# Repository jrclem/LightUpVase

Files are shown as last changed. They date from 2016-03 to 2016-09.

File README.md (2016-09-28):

# LightUpVase
This is an Arduino based project to control light colors and animationd in a 3D printed vase and rose. I originally made it for my girlfriend as an anniversary gift, but I thought people might like to make their own.

The project uses the [Adafruit NeoPixel library](https://github.com/adafruit/Adafruit_NeoPixel) and it has been tested in an Arduino Uno board with an ATmega328P processor. It is compatible with the [Adafruit ProTrinket 5v](https://www.adafruit.com/products/2000).

The STL files for the [vase](../master/rose-vase_FINAL.stl) and [flower](../master/rose-petals_FINAL.stl) models are based on models from www.thingiverse.com. The vase is a remix of ["Wave Vase" by didierkl](http://www.thingiverse.com/thing:983438), and the flower is a remix of ["Make a rose for your girl" by hansliu](http://www.thingiverse.com/thing:663065). For more details about the 3D printing specifications visit my [thingiverse account](http://www.thingiverse.com/jrclem/designs). They will be available in the next few days.

A youtube playlist detailing the development process will be available [here](http://bit.ly/2cJCIvM).

###Operation:

1. Connect the power supply to the vase. (In this case using 5V, 2A)
2. Flip the slide switch to the "on" position. This will power the board and the NeoPixel Ring.
3. Click the pushbutton for less than 0.5s to flip through the vase's light animations.
4. Click the pushbutton for  more than 0.5s to flip through the flower's light animations.

*Note:*
Do not leave lights turned off while the slide switch in the "on" position for an extended period of time. The board will still be powered during this time.

###Supplies

1. 1x [Arduino ProTrinket 5v](https://www.adafruit.com/products/2000)
2. 1x [Arduino RGB Neopixel Ring 16x](https://www.adafruit.com/products/1463)
3. 1x [Arduino RGB Neopixel](https://www.adafruit.com/products/1260)
4. 1x 5.5mmx2.1mm female barrel jack power adapter
5. 1x slide switch
6. 1x 6mmx6mm push button
7. 1x 1000&mu;F capacitor
8. 2x 510&ohm; resistor
9. 3x battery contact plates (or a similar thin conductive metal)
10. 1x 5v, 2A power supply with 5.5mmx2.1mm plug
11. \~250g translucent PLA
12. 22ga wire (green for the stem, the rest is up to you)
13. Cyanoacrylate glue and/or 5second Fix resin

###Assembly

1. Solder 3 green wires to the 5v, Din, and GND leads in the single Neopixel.
 * Make sure the wires are at least 180cm long to account for the twisting.
2. Insert Neopixel and cable through stem. Strip wires and glue exposed wires to the groves in the stem.
 * Clockwise starting at the fin of the stem base: 5V, Din, and GND.
3. Glue the petals to the stem using plenty of CA glue.
4. Solder wires to the 5v, Din, and GND leads in the Neopixel Ring.
5. Solder wires to the 3 battery plates.
6. Cut and mold the plates to fit separately in the stem coupler.
7. Load [vase.ino](../master/vase.ino) into the ProTrinket.
8. Solder components to board according to the [schematics](../master/LightUpVase-Schematics.png).
 * Ensure that all components fit in the 3D printed insert while you trim and solder wires in place.
9. Glue the button, switch, power adaptor, and wired battery plates in place using CA glue or resin.
10. Screw the insert into the vase, and lightly glue in place.
11. Plug in and test the assmebly

----------
If you would like to donate to my Grad School Fund, you can do so via [GoFundMe](http://bit.ly/2dqhotO) or [Paypal](http://bit.ly/2d2jKQU).

Thank you very much for your support!

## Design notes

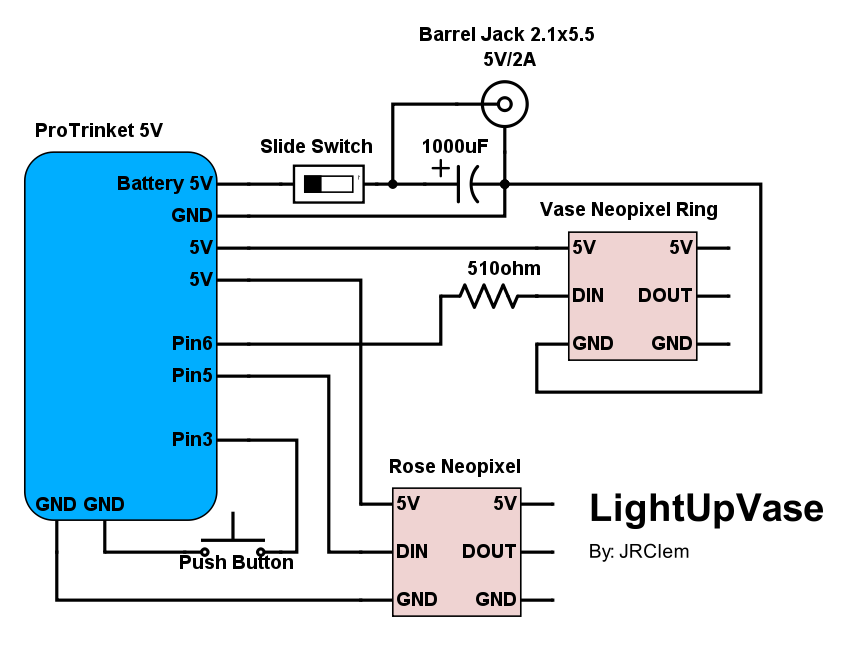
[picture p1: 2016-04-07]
LightUpVase-Schematics.png

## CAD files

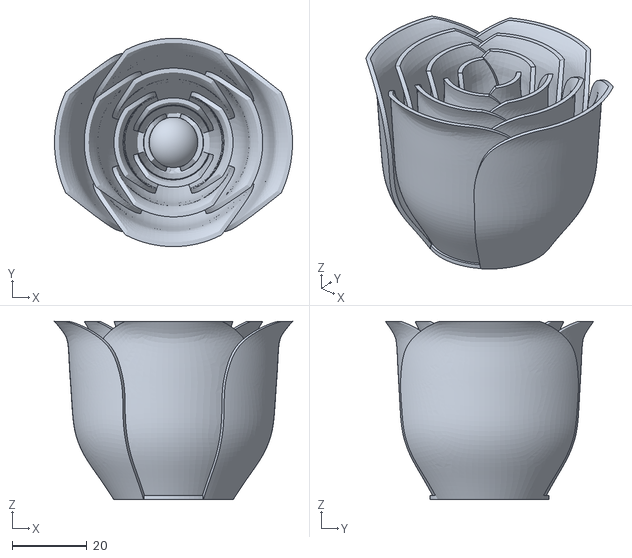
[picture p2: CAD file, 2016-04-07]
rose-petals_FINAL.stl
63.5 x 55.6 x 47.5

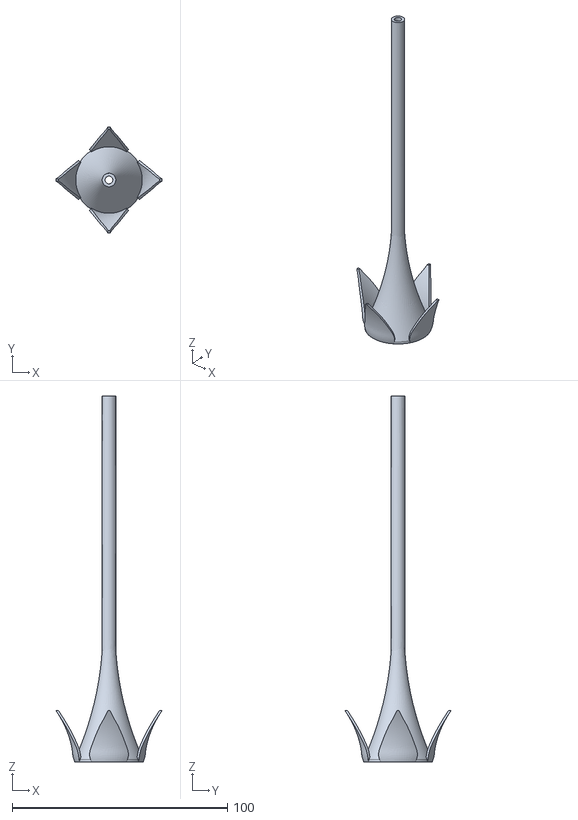
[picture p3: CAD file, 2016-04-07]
Rose-stem_FINAL.stl
49.2 x 49.2 x 170.0

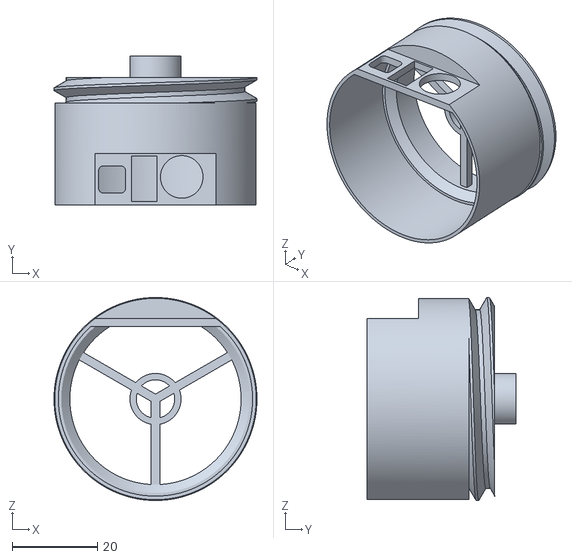
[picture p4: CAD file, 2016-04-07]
vase_insert_FINAL.stl
47.7 x 35.0 x 47.7

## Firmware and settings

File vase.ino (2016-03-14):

/* File:    vase.ino
 * By:      Jean René Clemenceau
 * Created: 03/06/2016
 * Controls a set of Adafruit Neopixels: One ring in the vase
 * and another single Neopixel to simulate a beating heart.
 * 
 * Some ring animations are incorporated from Adafruit's buttoncycler example.
 * 
 * Operation:
 * Short press the button to cycle though vase animations and colors.
 * Long press the button to cycle through heartbeat animations.
*/
#include <Adafruit_NeoPixel.h>

//Settings constants
const int ANALOG_MAX = 255;               //Highest possible PWM analog output value (max brightness)
const byte BPM_MAX = 61;                  //Heart's maxmimum beats per minute before strobing effect
const byte BPM = 21;                      //Heart's default beats per minute
const int BUTTON_PRESS_THRESHOLD = 500;  //Button press time that determines which lights settings to change

//Set pins
const byte BUTTON_PIN =  3;   //Digital IO pin connected to the button.
const byte HEART_PIN = 5;     //Digital IO pin number that represents heart
const byte RING_PIN =   6;    //Digital IO pin connected to the vase's NeoPixel ring.

//Initialize NeoPixels
const byte PIXEL_COUNT = 16;  //Number of NeoPixels in vase's ring
Adafruit_NeoPixel VASE_RING = Adafruit_NeoPixel(PIXEL_COUNT, RING_PIN, NEO_GRB + NEO_KHZ800 );  //Set vase
Adafruit_NeoPixel HEART = Adafruit_NeoPixel(1, HEART_PIN, NEO_GRB + NEO_KHZ800 );               //Set heart

//Mode tracker for heart
byte heart_rate;               //Determines variable heart rate
uint32_t heart_color;         //Determines color of heart NeoPixel

//Mode trackers for button input
bool old_state;               //Tracks the previous state of the input button
byte heart_mode;              //Marks the upcoming heartbeat mode for frequency and color
byte vase_mode;               //Marks the vase mode for color and animations


//Time trackers for non-blocking delays
unsigned long button_timer;    //Tracks time of previous button event

unsigned long beat_timer;     //Tracks time of previous beat for heartbeat delay
int beat_delay;               //Determines non-blocking wait time
byte heart_iteration;         //Tracks which stage the heartbeat is on
int dimmer;                   //Tracks the brightness value at dimming stage

unsigned long vase_timer;     //Tracks start time of previous vase light animation
int vase_delay;               //Determines non-blocking wait time
byte vase_anim_iteration;     //Tracks which stage the vase light animation is on

  
/***************************************************/

void setup() {
  //Initialize Pins
  pinMode(BUTTON_PIN, INPUT_PULLUP); //(HIGH = unpressed, LOW = pressed)
  pinMode(HEART_PIN, OUTPUT);
  pinMode(RING_PIN, OUTPUT);

  // Initialize all Neopixels to 'off'
  VASE_RING.begin();
  VASE_RING.show(); 
  HEART.begin();
  HEART.show();

  //Initialize heart light status
  heart_rate = BPM;
  heart_color = HEART.Color(255,0,0);

  //Initialize mode variables
  old_state = HIGH;
  heart_mode = 1;
  vase_mode = 0;

  //Initialize delay variables
  button_timer = 0;
  
  beat_timer = 0;
  beat_delay = 0;
  heart_iteration = 0;
  dimmer = ANALOG_MAX;
  
  vase_timer = 0;
  vase_delay = 0;
  vase_anim_iteration = 0;
}

void loop() {
  //check button state and time.
  bool new_state = digitalRead(BUTTON_PIN);
  unsigned long current_press_time = millis();
  bool buttonLifted = old_state == LOW && new_state == HIGH;
  bool shortPress = current_press_time - button_timer < BUTTON_PRESS_THRESHOLD;

  //If button lifted before threshold, change vase state (short press)
  if( shortPress && buttonLifted){
    vase_mode++;
    vase_anim_iteration = 0;
  }
  //If button lifted after more than threshold, change heart state (long press)
  else if( !shortPress && buttonLifted ){
    heart_mode = change_heart_state(heart_mode, heart_rate, heart_color, HEART);
  }
  //If button state changes, record change
  if( old_state != new_state ){
    button_timer = current_press_time;
    old_state = new_state;
  }

  //Execute heartbeat
  if(wait(beat_delay,beat_timer) ){
    beat_delay = heartbeat(heart_rate, HEART, heart_color, heart_iteration,dimmer);
  }

  //Animate Vase
  animate_vase(vase_mode, VASE_RING, vase_timer, vase_anim_iteration );
}


/**********Handling functions************/

/*heartbeat: animates an Adafruit NeoPixel to look like a heartbeat without blocking delays
 * Input
 *  -bpm:         (byte) Desired beats per minute.
 *  -pixel:       (Adafruit_NeoPixel) NeoPixel object containing the LED representing a heart.
 *  -neopix_color:(uint32_t) NeoPixel Color for the heartbeat.
 *  -iteration:   (byte) iterative stage of heartbeat.
 *  -dimmer:      (int) Brightness of NeoPixel during relaxation stage.
 * Output
 * The delay needed until the next heartbeat stage. (int)
*/
int heartbeat(byte bpm, Adafruit_NeoPixel &pixel, uint32_t neopix_color, byte &iteration, int &dimmer){
  int returnDelay = 0;                                        //Wait time until next stage

  //Turn off if BPM is less than 1
  if(bpm < 1){
    pixel.setPixelColor(0, 0);
    pixel.show();
    returnDelay = 0;
    iteration = 0;
  }
  //Turn on solid if BPM is greater than Max
  else if(bpm >= BPM_MAX){
    pixel.setPixelColor(0, neopix_color);
    pixel.show();
    returnDelay = 0;
    iteration = 0;
  }
  //Proceed to heartbeat stages if BPM is within range
  else{
    int interval = (60/bpm)*1000;                             //Total time of beat period
    int beat = interval/15;                                   //length of contraction
    int lag = interval/20;                                    //Lenth of time between beats
    int hb_attenuation = (interval/3) / ANALOG_MAX;           //Fade after ventricular delay offset
    int leftover_time = interval - (beat+lag+hb_attenuation); //Remainder of beat duration
    
    switch(iteration){
      case 0:
        //Start Atrial contraction
        pixel.setPixelColor(0, neopix_color);
        pixel.show();
        returnDelay = beat;
        iteration++;
        break;
      case 1:
        //Stop Atrial contraction
        pixel.setPixelColor(0,0);
        pixel.show();
        returnDelay = lag;
        iteration++;
        break;
      case 2:
        //Start Ventricular contraction
        pixel.setPixelColor(0, neopix_color);
        pixel.show();
        returnDelay = beat;
        iteration++;
        break;
      case 3:
        //Relax contraction gradually until finished
        if(dimmer > 0){
          pixel.setBrightness(dimmer);
          pixel.show();
          dimmer--;
        }else{
          //Reset dimmer and set next stage
          iteration++;
          dimmer = ANALOG_MAX;
        }
        returnDelay = hb_attenuation;
        break;
      case 4:
        //Wait for next beat
        pixel.setBrightness(ANALOG_MAX);
        pixel.setPixelColor(0,0);
        pixel.show();
        returnDelay = leftover_time;
        iteration=0;
        break;
      default:
        //If no recognized stage, reset.
        iteration=0;
        returnDelay = 0;
        break;
    }
  }
  return returnDelay;
}

/*change_heart_state: applies settings for different heartbeat animations
 * Input
 *  -i:           (byte) Heartbeat mode to be applied.
 *  -bpm:         (byte) Current beats per minute.
 *  -neopix_color:(uint32_t) Current NeoPixel Color for the heartbeat.
 *  -pixel:       (Adafruit_NeoPixel) NeoPixel object containing the LED representing a heart.
 * Output
 * The next heartbeat mode. (byte)
*/
byte change_heart_state(byte i, byte &bpm, uint32_t &neopix_color, Adafruit_NeoPixel &pixel) {
  byte new_state = i;
  switch(i){
    case 0: 
      //Default heart rate, Red color
      bpm = BPM;
      neopix_color = pixel.Color(255,0,0);
      new_state++;
      break;
    case 1:
      //Default heart rate, Blue color
      bpm = BPM;
      neopix_color = pixel.Color(0,0,255);
      new_state++;
      break;
    case 2:
      //Solid, Red color 
      bpm = BPM_MAX;
      neopix_color = pixel.Color(255,0,0);
      new_state++;
      break; 
    case 3:
      //Solid, Blue color
      bpm = BPM_MAX;
      neopix_color = pixel.Color(0,0,255);
      new_state++;
      break;
    case 4:
      //Solid, White color
      bpm = BPM_MAX;
      neopix_color = pixel.Color(255,255,255);
      new_state++;
      break;
    case 5:
      //off
      bpm = 0;
      new_state = 0;
      break;
     default:
      //Default heart rate, Red color
      bpm = BPM;
      neopix_color = pixel.Color(255,0,0);
      new_state = 0;
      break;
  }
  return new_state;
}

/*animate_vase: executes light animation of an Adafruit NeoPixel ring according to an indexed list.
 * Input
 *  -vase_animation:  (byte) Number that maps to animation type.
 *  -pixel:           (Adafruit_NeoPixel) NeoPixel object containing the LED ring.
 *  -vase_timer:      (unsigned long) Start time of previous animation step.
 *  -iteration:       (byte) counter for animation steps.
 * Output
 * None
*/
void animate_vase(byte vase_animation, Adafruit_NeoPixel &pixel, unsigned long &vase_timer, byte &iteration ) {
  unsigned long curr_time = millis();
  switch(vase_animation % 7){
    case 0:                                                 //Rainbow
      if(wait(80,vase_timer) ){
          vase_timer = curr_time;
          iteration = rainbow( VASE_RING, iteration);
      }
      break;
    case 1:                                                 //Cycle Rainbow
      if(wait(20,vase_timer) ){
            vase_timer = curr_time;
            iteration = rainbowCycle(VASE_RING, iteration);
      }
      break; 
    case 2:                                                 // Red
      if(wait(50,vase_timer) ){
        vase_timer = curr_time;
        iteration = floodRing(pixel.Color(255, 0, 0), pixel, iteration);
      }
      break;
    case 3:                                                 // Green
      if(wait(50,vase_timer) ){
        vase_timer = curr_time;
        iteration = floodRing(pixel.Color(0, 255, 0), pixel, iteration);
      }
      break;
    case 4:                                                // Blue
      if(wait(50,vase_timer) ){
        vase_timer = curr_time;
        iteration = floodRing(pixel.Color(0, 0, 255), pixel, iteration);
      }
      break;
    case 5:                                                 // White
      if(wait(50,vase_timer) ){
        vase_timer = curr_time;
        iteration = floodRing(pixel.Color(255, 255, 255), pixel, iteration);
      }
      break;
    case 6:                                               // Black/off
      if(wait(20,vase_timer) ){
        vase_timer = curr_time;
        iteration = floodRing(pixel.Color(0, 0, 0), pixel, iteration);
      }
      break;
    default:
      iteration = floodRing(pixel.Color(0, 0, 0), pixel, iteration);
      break;
  }
}

/*floodRing: floods a NeoPixel ring with chosen color of light one by one.
 * Input
 *  -color: (uint32_t) Color in NeoPixel 32bit format.
 *  -pixel: (Adafruit_NeoPixel) NeoPixel object containing the LED ring.
 *  -i:     (byte) current iteration of the loop.
 * Output
 * Next iteration of the loop. (bool)
*/
byte floodRing(uint32_t color, Adafruit_NeoPixel &pixel, byte i) {
  if(i < pixel.numPixels() ){
    pixel.setPixelColor(i, color);
    pixel.show();
    i++;
  }
  return i;
}


/*wait: determines if enough time has passed since last indicated. Used for non-blocking delays.
 * Input
 *  -wait_time:      (unsigned long) amount of miliseconds delayed.
 *  -last_performed: (unsigned long) time at which the event was last executed (miliseconds relative to start of script).
 * Output
 * Wether the specified miliseconds have passed since the last execution or not. (bool)
*/
bool wait(unsigned long wait_time, unsigned long &last_performed){
  unsigned long current = millis();
  bool wait_done = false;
  if( (current - last_performed) >= wait_time ){
    last_performed = current;
    wait_done = true;
  }
  return wait_done;
}


/*******ADAPTED ADAFRUIT FUNCTIONS*********/

//Cycles through all colors available with RGB using all pixels in the ring
byte rainbow(Adafruit_NeoPixel &pixel, byte j) {
  //Cycle through colors
  if(j<256) {
    //Set all pixels
    for(uint16_t i=0; i<pixel.numPixels(); i++) {
      pixel.setPixelColor(i, Wheel((i+j) & 255, pixel));
    }
    pixel.show();
    j++;
  }
  return j;
}

// Slightly different, this makes the rainbow equally distributed throughout
byte rainbowCycle(Adafruit_NeoPixel &pixel, byte j) {
  if(j<256) {
    for(uint16_t i=0; i< pixel.numPixels(); i++) {
      byte k = 256 - j;
      pixel.setPixelColor(i, Wheel(((i * 256 / pixel.numPixels()) + k) & 255, pixel));
    }
    pixel.show();
    j++;
  }
  return j;
}

// Input a value 0 to 255 to get a color value.
// The colours are a transition r - g - b - back to r.
uint32_t Wheel(byte WheelPos, Adafruit_NeoPixel &pixel ) {
  WheelPos = 255 - WheelPos;
  if(WheelPos < 85) {
    return pixel.Color(255 - WheelPos * 3, 0, WheelPos * 3);
  }
  if(WheelPos < 170) {
    WheelPos -= 85;
    return pixel.Color(0, WheelPos * 3, 255 - WheelPos * 3);
  }
  WheelPos -= 170;
  return pixel.Color(WheelPos * 3, 255 - WheelPos * 3, 0);
}

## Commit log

2016-03-14 Add Main File
    Added vase.ino, the file containing the software for the vase's control board
2016-04-07 Update README.md
    Added details for assembly, supplies, fixed formatting and spelling
2016-04-07 Added files via upload
    Added STL files for 3D printed parts. Added schematics for electronics
    [Rose-stem_FINAL.stl, rose-petals_FINAL.stl, vase_insert_FINAL.stl]
2016-04-07 Update README.md
    updated details about assembly, STL files, and the origin of the project. Added relevant links. Spelling and Formatting.
